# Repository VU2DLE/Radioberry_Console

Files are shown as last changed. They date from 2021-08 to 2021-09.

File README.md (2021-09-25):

<p align="center">
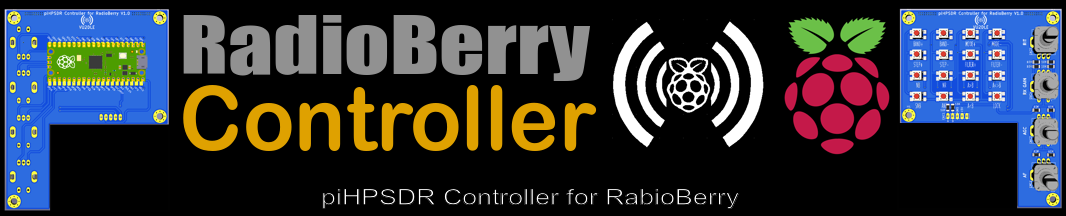
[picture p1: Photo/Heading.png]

</p>

Radioberry Controller is very simple standalone console for piHPSDR, which is designed only for RadioBerry SDR project. A simple way to control piHPSDR using hardware controls mounted in front panel. Both software and hardware initial version is ready to use, but still development is progressing, new features may get added and bugs being fixed. 

My sincere thanks to Johan for the RadioBerry SDR project, John Melton for piHPSDR.
Rama VU3RDD and Deepu VU3TLD for suggestions and design reviews from the beginning of this project.

## Version V1.0 Features
* VFO controlled by single optical encoder
* AF, AGC, RX GAIN and RIT controlled by 4 mechanical encoders
* Push Switch controls for
  * Band+, Band–
  * Mode+, Mode-
  * Step+, Step–
  * Filter+, Filter–
  * Noise functions: NB, NR ANF and SNB
  * VFO functions: VFO A to B, VFO B to A, VFO swap and Lock

## How it works
Radioberry Controller (RBC) PCB and Raspberry Pi Pico (Pico) works from the Raspberry Pi's (RPI) USB power. Pico is the part of RBC, and connects to the RPI using a USB cable. RBC takes 5V from the USB, so no need of external DC power. RBC reads the user events like switch press and movement of rotary encoder via GPIO's of the Pico. These user inputs are processed by Pico and send to Raspberry Pi via USB interface.
In RPI, application software rbc_comm, which receives the user response commands (like clicking switches or rotation of vfo encoder) via USB and send appropriate CAT commands to piHPSDR. USB serial adapter may appear as /dev/ttyACM0 in RPI, after pluging in Pico via USB cable.
<p align="center">
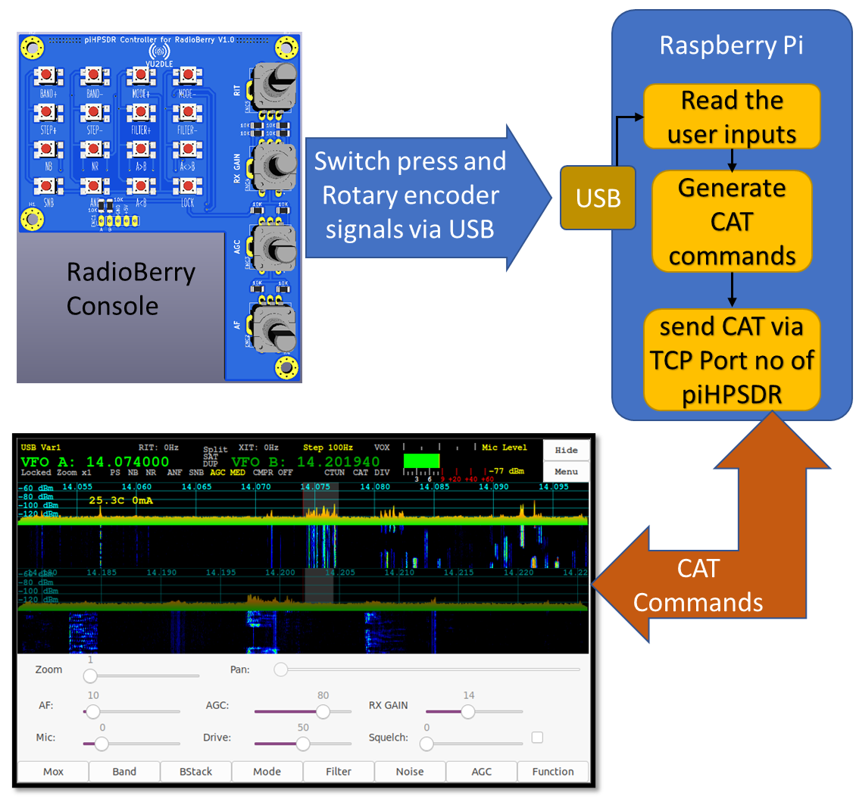
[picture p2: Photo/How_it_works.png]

</p>

## Hardware
Hardware is very simple. Solder the 4 mechanical encoder and 16 push buttons switch on the top of the PCB, also place the 10K resistors.
<p align="center">
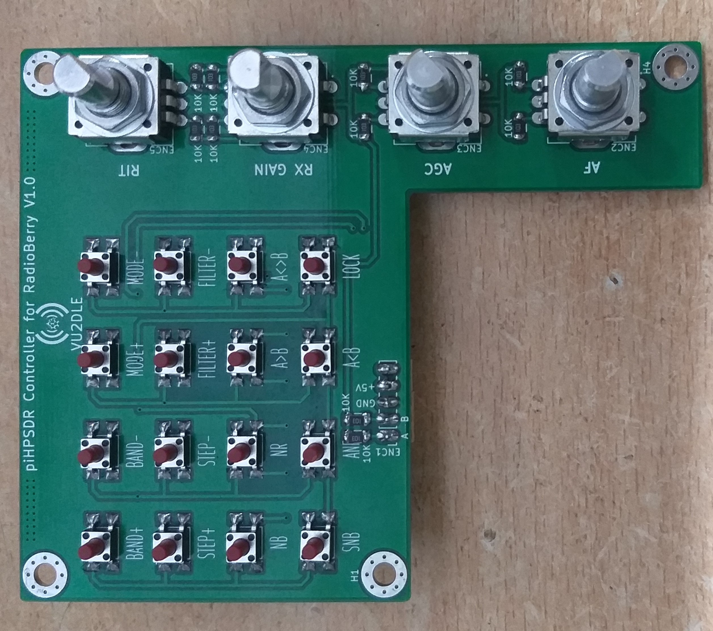
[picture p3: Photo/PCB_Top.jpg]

</p>
At the bottom, use appropriate PCB Receptacles Female Box Header Connector for placing the Raspberry Pi Pico. Luckily, I got cheap inexpensive connectors from local shop. Take 2 sets of, 18 way 1 row straight PCB female socket, through hole type. Carefully bend the leads 90degree and solder them.
<p align="center">
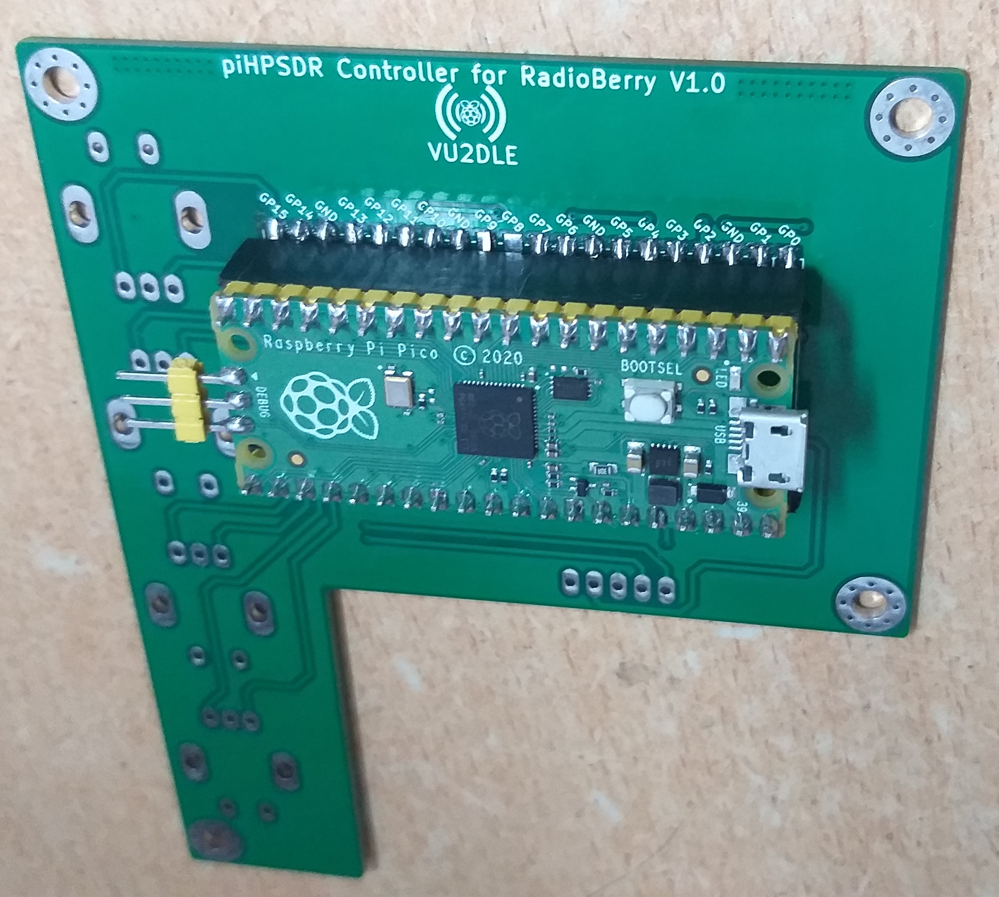
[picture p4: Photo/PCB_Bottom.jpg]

</p>

### Completely assembled PCB with optical rotary encoder
<p align="center">
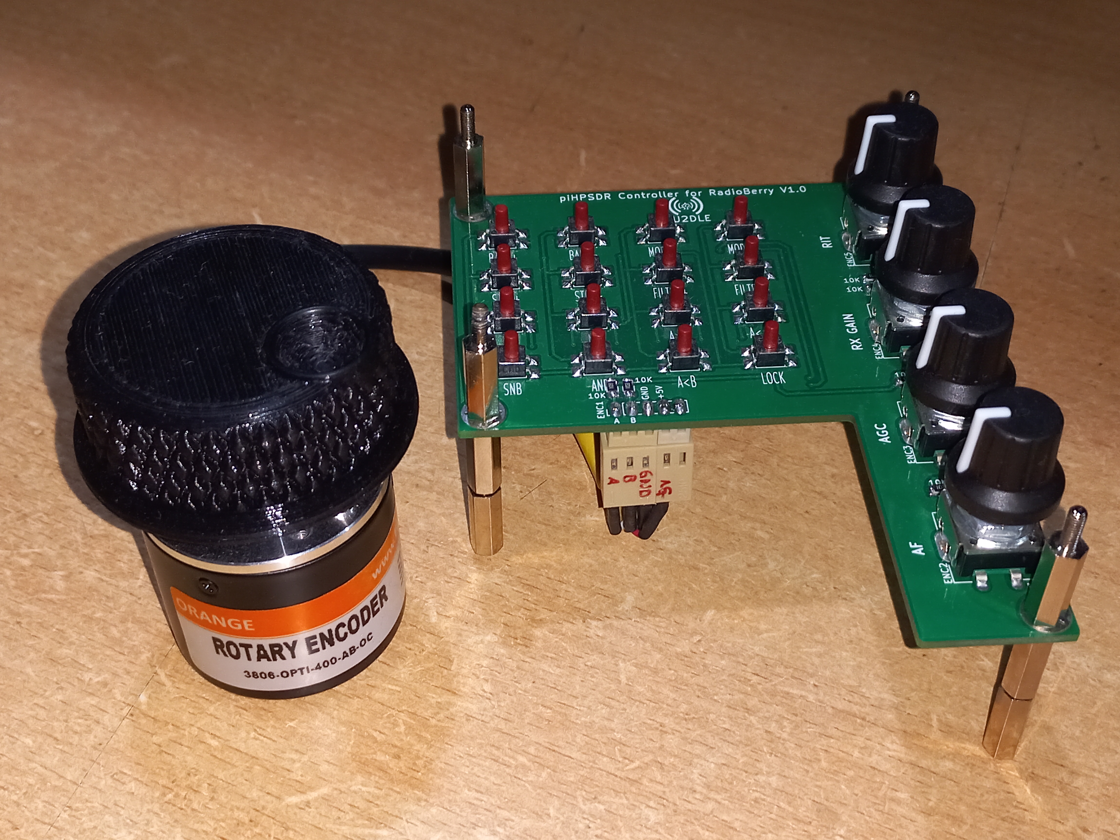
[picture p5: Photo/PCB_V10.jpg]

</p>

## Software Installation
Create a directory in your raspberry pi under the /home/pi. 
Open a command window and executing the following commands:
```ruby
cd /home/pi/
mkdir rbc_main
cd rbc_main
git clone https://github.com/VU2DLE/Radioberry_Console.git
```
### Step1: Flashing the firmware
Flashing the firmware in Pico is simple. Easy method is, if you hold down the BOOTSEL button when you plug in your Pico, it will appear as a drive onto which you can drag UF2 file. The binary file: rb_controller.uf2, is available in the folder rbc_main \Radioberry_Console\Software\Firmware\bin.
### Step2: Building the Application
Go to the folder “Application”
```ruby
cd /home/pi/rbc_main/Radioberry_Console/Software/Application/
make clean
make
```
### Step3: Rebuild the piHPSDR
There are few changes I have done in the rigctl.c of the piHPSDR, which is essential. since my pull request is not yet part of the /g0orx/pihpsdr, you can use the forked pihpsdr from my github.
Simple method to rebuild the piHPSDR is by editing pihpsdr_install.sh from Johan. Follow the steps of Johan for installing piHPSDR sofware.
Before executing “sudo chmod +x pihpsdr_install.sh”, open the pihpsdr_install.sh in any editor you are familiar, then remove line “git clone https://github.com/g0orx/pihpsdr.git”. Add “git clone https://github.com/VU2DLE/pihpsdr.git”. Save and close the pihpsdr_install.sh and continue remaining steps.

### Now software installation is completed.
Before executing the rbc_comm, make sure that radioberry is running and also pihpsdr. In pihpsdr, goto Menu->RIGCTL. rbc_comm program communicate piHPSDR via this TCP Port number 19090. Select Rigctl Enable tick mark and Rigctl Port Number is 19090.

Now Open a command window and execute the program
```ruby
cd /home/pi/rbc_main/Radioberry_Console/Software/Application/
./rbc_comm
```
Now you see the following output in the command window
```ruby
/*******************************************/
/**          W E L C O M E                **/
/**               T O                     **/
/**  piHPSDR Controller for Radioberry    **/
/**               V1.0                    **/
/**-------------------------------------- **/
/**          DE VU2DLE Dileep             **/
/*******************************************/
```

Radioberry_Console (https://www.youtube.com/watch?v=Wp12q2RIvMo)

Enjoy and Happy Homebrewing….

Many 73s
DE VU2DLE Dileep

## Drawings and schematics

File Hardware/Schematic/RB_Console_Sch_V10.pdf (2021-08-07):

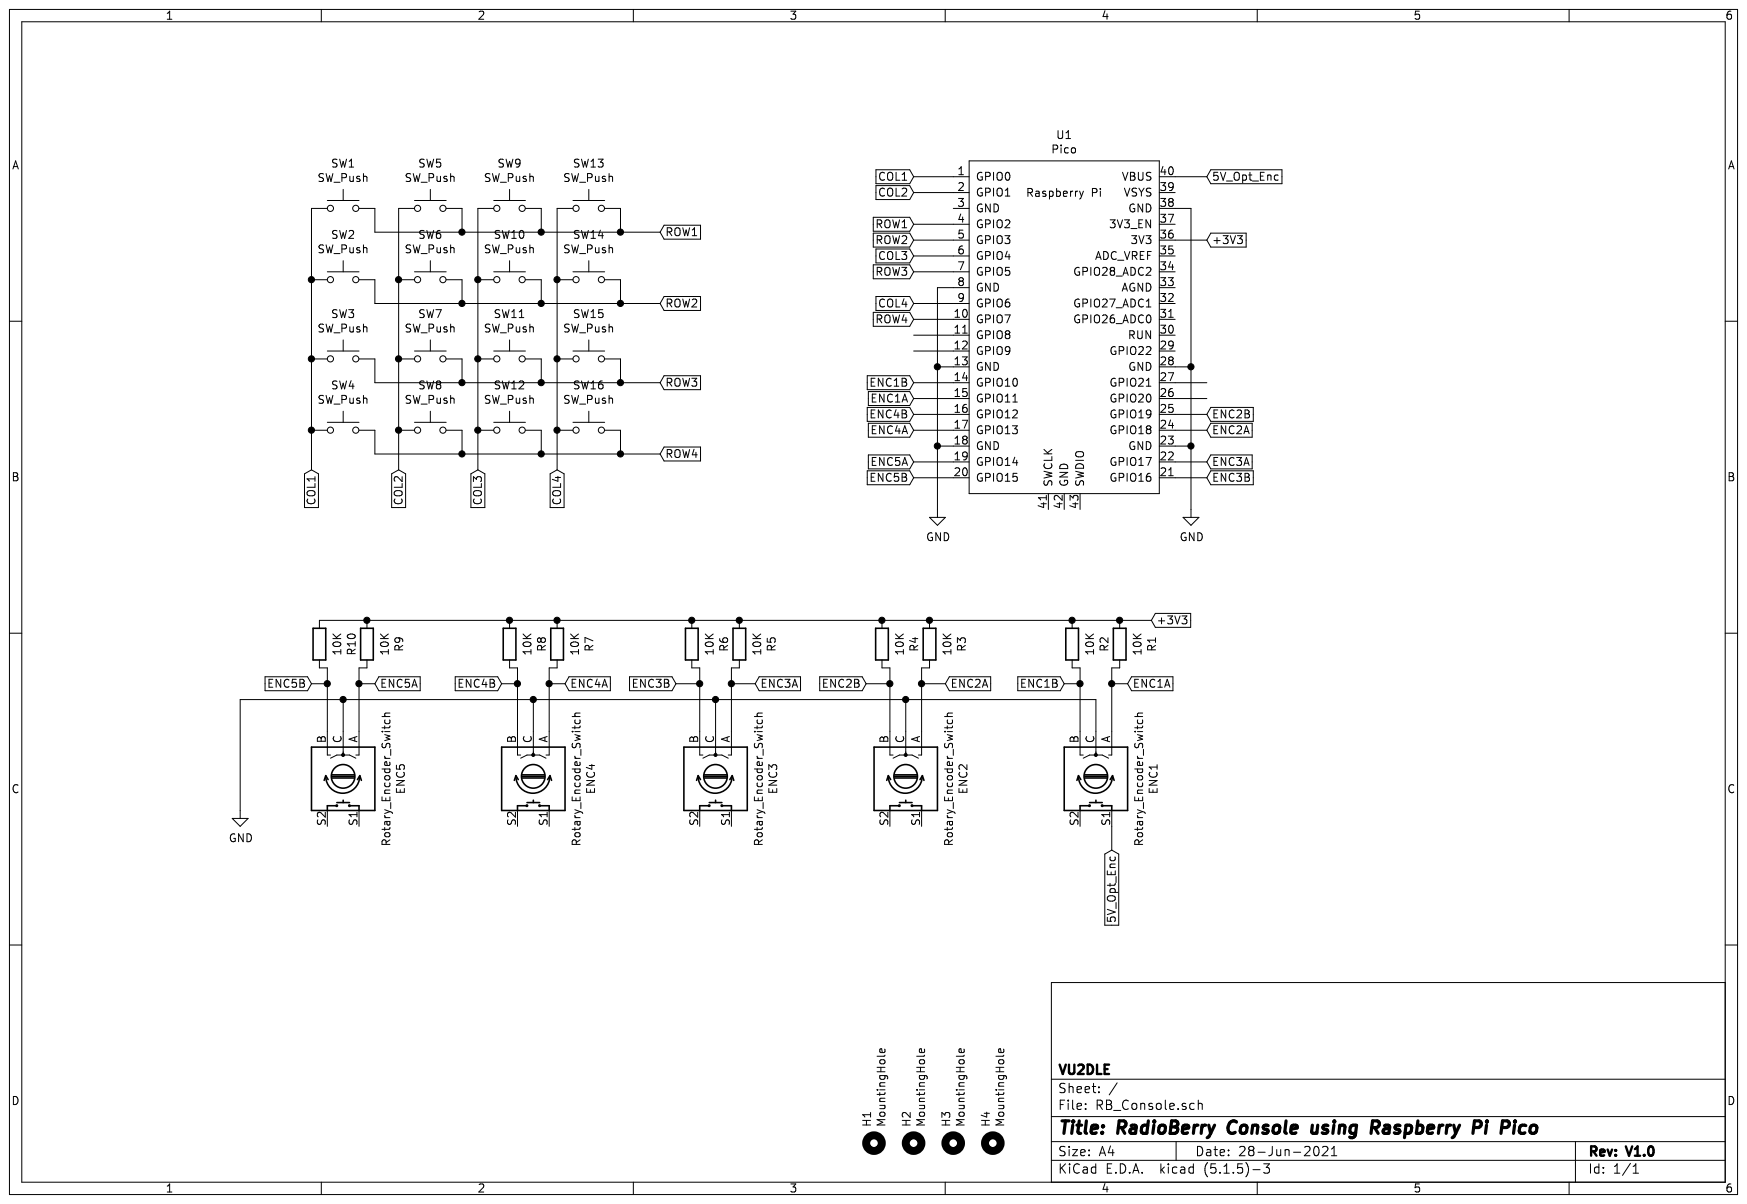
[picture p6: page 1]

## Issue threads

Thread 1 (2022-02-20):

Compile Radioberry console on Rpi4

PeWa1, 2022-02-20:
I  have problem to find lpthread and lwiringPi on Raspberry Debian Bullseye 64bit
WiringPi seams to exclude lib files, can you post them here ?

VU2DLE, 2022-02-23:
OM SM6NTR,

I haven't tried the latest build for rpi4. would you mind giving details about the latest build? then I can re-create the same issue that you are facing, which may help me to solve issue fast.

My RPI is RPI4B

My RPI4 OS Version:
pi@raspberrypi:~ $ cat /etc/os-release
PRETTY_NAME="Raspbian GNU/Linux 10 (buster)"
NAME="Raspbian GNU/Linux"
VERSION_ID="10"
VERSION="10 (buster)"
VERSION_CODENAME=buster
ID=raspbian
ID_LIKE=debian
HOME_URL="http://www.raspbian.org/"
SUPPORT_URL="http://www.raspbian.org/RaspbianForums"
BUG_REPORT_URL="http://www.raspbian.org/RaspbianBugs"

I'm getting no clue on how "multiple definition of buffer" issues are popping. could you please try following commands in rpi4 and let me share your log?

cd /home/pi/rbc_main/Radioberry_Console/Software/Application/
make clean
make

Many 73s
DE VU2DLE Dileep

PeWa1, 2022-02-23:
Hello Dileep
Here is my setup

pi@raspberrypi:~ $ cat /etc/os-release
PRETTY_NAME="Raspbian GNU/Linux 11 (bullseye)"
NAME="Raspbian GNU/Linux"
VERSION_ID="11"
VERSION="11 (bullseye)"
VERSION_CODENAME=bullseye
ID=raspbian
ID_LIKE=debian
HOME_URL="http://www.raspbian.org/"
SUPPORT_URL="http://www.raspbian.org/RaspbianForums"
BUG_REPORT_URL="http://www.raspbian.org/RaspbianBugs"

Consol text from make

pi@raspberrypi:~/rbc_main/Radioberry_Console/Software/Application $ make clean
Cleaning up...
rm -rf rbc_comm.o button.o rbc_comm
pi@raspberrypi:~/rbc_main/Radioberry_Console/Software/Application $ make
gcc -c rbc_comm.c button.c -lpthread -lwiringPi
gcc -o rbc_comm rbc_comm.o button.o -lpthread -lwiringPi
/usr/bin/ld: button.o:(.bss+0x0): multiple definition of `buffer'; rbc_comm.o:(.bss+0x254): first defined here
/usr/bin/ld: button.o:(.bss+0x118): multiple definition of `n'; rbc_comm.o:(.bss+0x14): first defined here
collect2: error: ld returned 1 exit status
make: *** [Makefile:5: rbc_comm] Error 1
pi@raspberrypi:~/rbc_main/Radioberry_Console/Software/Application $ ls -l
total 44
-rw-r--r-- 1 pi pi 6273 Feb 20 15:26 button.c
-rw-r--r-- 1 pi pi   47 Feb 20 15:26 button.h
-rw-r--r-- 1 pi pi 9068 Feb 23 17:40 button.o
-rw-r--r-- 1 pi pi  200 Feb 20 15:26 Makefile
-rw-r--r-- 1 pi pi 6267 Feb 20 15:26 rbc_comm.c
-rw-r--r-- 1 pi pi 6912 Feb 23 17:40 rbc_comm.o
pi@raspberrypi:~/rbc_main/Radioberry_Console/Software/Application $

rems78, 2022-06-08:
for wiring pi , the solution could be here :
http://wiringpi.com/wiringpi-updated-to-2-52-for-the-raspberry-pi-4b/
but i still have alot of errror during compilation.
thus i start a new install from radioberry on RPI4 with ''old '' os.
https://www.raspberrypi.com/software/operating-systems/
os buster  32 bits
Raspberry Pi OS (Legacy) with desktop Release date: April 4th 2022
System: 32-bit Kernel version: 5.10 Debian version: 10 (buster)
Size: 751MB

no need to upgrade wiring pi during VU2DLE software installation
Installation seem to be ok, now

PeWa1, 2022-07-11:
Hello Dileep
I have testing the Console little more now , and I have notice some software stops during test
the sound also stop and the communication to Rapsbery pico stops , this is shortly around som minutes of using, today i connected to the local ip 127.0.0.1 on radioberry and then the panel software it runs Ok the whole day but i testet the volume control after some hours and it still runs OK , i wonder if you have seen any problems that i have, Pico software stops and sound stops sometime , the sound can however be restared from the pihpsdr menu sound on/off , but the pico sofware i have to start from run again is there any different to start pihpsdr from 127.0.0.1 or the network 192.168.xxx.xxx adress, i dont think so ? what is the most sensetive stop for pico software to pihpsdr can it be more robust communication ?  best 73 Peter / SM6NTR

rems78, 2023-02-11:
Hello
The only issu I have is  comming from the pihpsdr with rbc : ''pihpsdr mic_read_thread read from audio interface failed''
Message appears only if I start rbc_main, and if I use a mic in configuration.
Thus I can not use rbc and this hardware in transmit mode  :-(

rems78, 2023-02-16:
not really compilation issue, but  issue detected on RPI4 . With ''top'' command I discover that rbc_comm is using 200% of CPU. the mic mic_read_thread error in pihpsdr is canceled with audio mic on -off. Issue increase with Sample rate, duplex,  and if rbc-com is started.
is this ''200% cpu '' understandable? wrong indicator.?
best 73. Rémi  / F4BAD

OK2MTW, 2023-03-14:
Hello guys, I tried to compile app, and I had similar problem with multiple definition for variable n and buffer, both are in both *.c files. So I decided to change them in one of them and my compilation was successful. I am not tested it yet due to my HW will be finished  during a few days.
Martin OK2MTW

vu2iia, 2024-08-01:
HI Martin @OK2MTW
Thanks for the good tip, I was able to compile on "bullseye". Edited 'button.c' and code compiled fine, earlier had same issue of "multiple definition".
Mahesh-VU2IIA

SP2NNO, 2024-08-01:
Dear friend

1. I have a Raspberry Pi 4 with a 7-inch display, running Raspberry Pi OS. 

2. Additionally, I have installed a Radioberry board and the appropriate software.

3. I have installed pihpsdr, which works well. 

4. I also downloaded the software from https://github.com/VU2DLE/Radioberry_Console.git.

5. I ordered a PCB for the RBC controller, where I mounted all the components along with the Pi Pico processor, which has the rb_firmware_v10.uf2 program uploaded.

6. According to your instructions, I tried to compile the RBC application. However, I encountered an error due to the missing wiringPi library in the operating system. 

7. I found and installed the wiringpi-2.61-1-arm64.deb library.
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
SP2NNO, 2024-09-18:
Hello everyone on the forum. The lack of activity was due to the fact that I had just finished heart surgery. Yes, the console works flawlessly, only thanks to the help of my friend Bartek SP3CAI.  Dimitrij, if you still haven't solved the problem, please contact me at: marekfoterek@wp.pl and you will receive a file with the entire manual and a ready-made processor input by SP3CAI. Regards, Marek SP2NNO

UT4NJ, 2024-09-18:
Marek, I wrote to your e-mail, thank you in advance.
Regards Dima. UT4NJ. 73!!! GL!!!

UT4NJ, 2024-09-19:
I'm trying to just record on Pico according to SP3CAI instructions, it doesn't work, I must be completely dumb. I copied micropython-12-JAN-2021.uf2 file to Pico, disconnected and connected Pico, disk does not appear.
Tried several Pico boards, I don't see the disk.
What is my mistake?

DO7CZ-Christian, 2024-09-19:
Hallo Marek, ich habe da gleiche Problem wie Dima UT4NJ.
Ich würde dir auch eine E-Mail schreiben.
Christian DO7CZ 73.

DO7CZ-Christian, 2024-09-19:
Ich erhalte folgende Meldung

**pi@sdr:~/rbc_main/Radioberry_Console/Software/Application $** make
gcc -c rbc_comm.c button.c -lpthread -lwiringPi
gcc -o rbc_comm rbc_comm.o button.o -lpthread -lwiringPi
/usr/bin/ld: button.o:(.bss+0x0): multiple definition of `buffer'; rbc_comm.o:(.bss+0x254): first define  d here
/usr/bin/ld: button.o:(.bss+0x118): multiple definition of `n'; rbc_comm.o:(.bss+0x14): first defined he  re
collect2: error: ld returned 1 exit status
make: *** [Makefile:5: rbc_comm] Fehler 1
**pi@sdr:~/rbc_main/Radioberry_Console/Software/Application $** ls
button.c  button.h  button.o  Makefile  rbc_comm.c  rbc_comm.o

UT4NJ, 2024-09-20:
I tried again according to SP3CAI instructions, after copying micropython-12-JAN-2021.uf2 file to Pico disk does not appear, tried copying adafruit-circuitpython-raspberry_pi_pico-ru-9.1.4.uf2 to Pico , everything is fine CIRCUITPY disk appears.
Is it possible to do further steps in this variant ? and why I don't have CIRCUITPY disk after copying micropython-12-JAN-2021.uf2 ??? ?

sp3cai, 2024-09-20:
1. Read carefully, especially "installing CircuitPython"
   and "Creating and editing Code" from:

   https://learn.adafruit.com/welcome-to-

2  Download uf2 file from:

   https://circuitpython.org/board/raspberry_pi_pico/

   this is: adafruit-circuitpython-raspberry_pi_pico-en_US-9.1.4.uf2

3. Press key on Pico and connect to USB, then open key:

   You must see disk named RPI-RP2 (disk letter)

4. Drag uf2 file to this disk, then wait - new disk is open with name
   CIRCUITPY(disk letter)

5. Copy the contents of the lib directory to this disk (there should be
   an empty lib directory there), and the code.py file in the main 
   directory.

6. Turn Pico off and on.

7. Look for the COM port that appears when you turn on Pico. Now
   you can monitor the program running on this COM using a terminal  
   program, for example PuTTY (set the port speed to 115200).

8. If everything is OK, you can enable Pico in pihpsdr, and configure via
   the menu, midi tab, where you need to enable midi setting.
   Now, when you press a button, a detected event appears, which can be   
   assigned using a table to the appropriate pihpsdr function.
   The same is done by turning an encoder in turn.
   Details can be found in the pihpsdr manual.

   greetings from sp3cai.

sp3cai, 2024-09-20:
program You can found on:

https://framagit.org/remis732/pico2040midicontroller

DO7CZ-Christian, 2024-09-20:
vielen lieben dank für die Anleitung :+1:
bei mir hat es funktioniert :)
ich hoffe Dima du bekommst es auch zum laufen.
73 DO7CZ Christian und ein schönes Wochenende

lebalme2000, 2024-11-17:
Hello everyone,
I tried to install the VU2DLE solution but I can't do it because of a Wiring error that I don't know how to resolve. I then turned to the solution of a MIDI interface and there I succeeded - the Deelep hardware works well but I just have a problem with the RX GAIN which when I turn it directly puts the RX gain at 0 - I cannot increase the RX GAIN by turning the encoder.
Did you also have this problem, how did you resolve it?

UT4NJ, 2024-11-18:
Hi everyone! I have the same problem. I am not satisfied with the solution of this problem through Pihpsdr Midi and since I developed the controller VU2DLE, I think it would be very good if he solved this problem and updated the instructions for installing the controller. Not everyone knows how to work with code, many just repeat the design and do everything according to the author’s instructions. I strongly ask the author and I think many join my request that the developer update the manual. It is really very useful design and many repeat it and now have a problem. In advance thank you!
With respect to Dima UT4NJ.

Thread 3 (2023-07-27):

Any thoughts on using this with sBitx

elvisthedj, 2023-07-27:
Hello Dileep,

I have a few pcb's from this project, but never actually obtained a Radioberry. I do however have an sBitx 40 v2. I've seen messages from you on the uBitx mailing list from several years ago, so I thought you may have considered using this board with one of Ashar's radios. Have you? I would love to make this work with my sbitx. I'm currently designing the enclosure, so if you have any feedback, please reply.

Thanks and 73's from Montana, USA

VU2DLE, 2023-07-28:
Hello elvisthedj,

Thank you for your interest in my project. Unfortunately, I haven't considered sBitx or uBitx while designing my project. My focus was "only" for RadioBerry. I would be very happy if you can make necessary modifications to use my project for your sBitx/uBitx.

with you good luck for your enclosure designing!

Many 73s DE Dileep VU2DLE DL2AJ

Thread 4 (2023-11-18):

Facing same problem with instruction " make" .

PE1PWR, 2023-11-18:
Hi Balan,
Thanks for your great work you have done.
I have a same problem to use " **make**"  for the final the programming.

cd /home/pi/rbc_main/Radioberry_Console/Software/Application/
**make clean
make**
After **make** I get this error.

pi@raspberrypi:~/rbc_main/Radioberry_Console/Software/Application $ sudo make
gcc -c rbc_comm.c button.c -lthread -lwiringPi
gcc -o rbc_comm rbc_comm.o button.o -lthread -lwiringPi
/usr/bin/ld: button.o:(.bss+0x0): multiple definition of `buffer'; rbc_comm.o:(.bss+0x254): first defined here
/usr/bin/ld: button.o:(.bss+0x118): multiple definition of `n'; rbc_comm.o:(.bss+0x14): first defined here
/usr/bin/ld: cannot find -lthread
collect2: error: ld returned 1 exit status
make: *** [Makefile:5: rbc_comm] Fout 1

When I use Make in Get this information
CC = gcc

rbc_comm:
	${CC} -c rbc_comm.c button.c -lthread -lwiringPi
	${CC} -o rbc_comm rbc_comm.o button.o -lthread -lwiringPi
clean:
	@echo "Cleaning up..."
	rm -rf rbc_comm.o button.o rbc_comm

Terminal info:
./Makefile: 1: CC: not found
./Makefile: 3: rbc_comm:: not found
./Makefile: 4: -c: not found
./Makefile: 5: -o: not found
./Makefile: 6: clean:: not found
./Makefile: 7: @echo: not found
------------------
(program exited with code: 0)
Press return to continue

I am using Release date: May 3rd 2023
System: 32-bit
Kernel version: 6.1
Debian version: 11 (bullseye)
Size: 2,701MB

Hoop you can tell me what I am missing. Or how I can resolving this problem. I have allready make a compleet Red Pitaya transmitter. Now I like to make a compleet Radioberry from Johan also with your project.
PE1PWR
73s

PE1PWR, 2023-11-19:
Finaly I have made the same solution to compile it in a raspberry PI3 and copied the files to my Pi4. Everything works fine now. Diplee thanks for your good job.
PE1PWR
73's

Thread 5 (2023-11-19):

What version of RAspberry OS have you used for this project ?

DarrenRainer, 2023-11-19:
Hi Dileep,

 I have a working Raspberry Pi 4 using radioberry (16 version)  and Pihhpsdr . I have  followed your changes in the code to install the code for the console but get stuck because I am using 64bit raspberry pi desktop OS. I tried a 32bit version but then get told on installing raspberry OS that it is not compatible. Do I need to try this on a raspberry pi3 with 32bit OS or do I stick with the RAspberry PI 4 with 64bit OS ?

73s Darren G4VTQ

PE1PWR, 2023-12-02:
Hi Darren,
Try to type this in your config.txt
arm_bit64=0
I was facing the same problem. After that everything works.

By the way I have use a older Raspberry pi3 to makes that extra files for the controller. The program was developpe with Bullseye. I mean step 2 in readme. The newer OS can handle this point.
Step2: Building the Application
Go to the folder “Application”

cd /home/pi/rbc_main/Radioberry_Console/Software/Application/
make clean
make

Goodluck
PE1PWR Wim
73s

DarrenRainer, 2023-12-02:
Thanks Wim for the help. I will give it a go and see what happens. I have
both pi3 and pi4.

73s Darren

On Sat, 2 Dec 2023, 09:48 Wim Schilperoort, ***@***.***>
wrote:

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

PE1PWR, 2023-12-02:
Hi Darran,
I think this will help you. I was also some time busy to get the radioberry a live. If want to use this controller also you have use the PI3 with bullseye. If you use the instruction " make clean"  it will work on both pi3 and 4. But when you do the instruction " make"  its only works on a Pi3. What I have done after this files are made i have copied them to de pi4 in the correct folder Application under RBC_main/Radioberry_Console/Application. You will find there 7 files. When its not working after the instruction " make"  you only find 5 files.
I hope that you find a way to get it work. Its a nice project. I have now the Radioberry working. Also the controller Pico Pi and Arduino Nano for the right signals to handle the LPF and BPF relais. Some later I place pictures of the Radioberry on QRZ.com where you can also see my other project a Red Pitaya HF transmitter.
Good luck
PE1PWR
Wim
73's

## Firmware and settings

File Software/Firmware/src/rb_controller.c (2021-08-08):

/**************************************
 * piHPSDR Controller for Radioberry
 * firmware V1.0
 * DE VU2DLE Dileep
 **************************************/
#include <stdio.h>
#include "pico/stdlib.h"
#include "pico/sync.h"


#define ENC1A 11
#define ENC1B 10

#define ENC2A 18
#define ENC2B 19

#define ENC3A 17
#define ENC3B 16

#define ENC4A 13
#define ENC4B 12

#define ENC5A 14
#define ENC5B 15

#define KPR0 2 
#define KPR1 3
#define KPR2 5
#define KPR3 7

#define KPC0 0
#define KPC1 1
#define KPC2 4
#define KPC3 6
#define KPCX 99 // undefined column number!

uint32_t int_status;

//--------------------------------------------------------------------------
#define DIR_NONE 0x0
// Clockwise step.
#define DIR_CW 0x10
// Anti-clockwise step.
#define DIR_CCW 0x20

#define R_START 0x0
//#define HALF_STEP

#ifdef HALF_STEP
// Use the half-step state table (emits a code at 00 and 11)
#define R_CCW_BEGIN 0x1
#define R_CW_BEGIN 0x2
#define R_START_M 0x3
#define R_CW_BEGIN_M 0x4
#define R_CCW_BEGIN_M 0x5
const unsigned char ttable[6][4] = {
  // R_START (00)
  {R_START_M,            R_CW_BEGIN,     R_CCW_BEGIN,  R_START},
  // R_CCW_BEGIN
  {R_START_M | DIR_CCW, R_START,        R_CCW_BEGIN,  R_START},
  // R_CW_BEGIN
  {R_START_M | DIR_CW,  R_CW_BEGIN,     R_START,      R_START},
  // R_START_M (11)
  {R_START_M,            R_CCW_BEGIN_M,  R_CW_BEGIN_M, R_START},
  // R_CW_BEGIN_M
  {R_START_M,            R_START_M,      R_CW_BEGIN_M, R_START | DIR_CW},
  // R_CCW_BEGIN_M
  {R_START_M,            R_CCW_BEGIN_M,  R_START_M,    R_START | DIR_CCW},
};
#else
// Use the full-step state table (emits a code at 00 only)
#define R_CW_FINAL  0x1
#define R_CW_BEGIN  0x2
#define R_CW_NEXT   0x3
#define R_CCW_BEGIN 0x4
#define R_CCW_FINAL 0x5
#define R_CCW_NEXT  0x6

const unsigned char ttable[7][4] = {
  // R_START
  {R_START,    R_CW_BEGIN,  R_CCW_BEGIN, R_START},
  // R_CW_FINAL
  {R_CW_NEXT,  R_START,     R_CW_FINAL,  R_START | DIR_CW},
  // R_CW_BEGIN
  {R_CW_NEXT,  R_CW_BEGIN,  R_START,     R_START},
  // R_CW_NEXT
  {R_CW_NEXT,  R_CW_BEGIN,  R_CW_FINAL,  R_START},
  // R_CCW_BEGIN
  {R_CCW_NEXT, R_START,     R_CCW_BEGIN, R_START},
  // R_CCW_FINAL
  {R_CCW_NEXT, R_CCW_FINAL, R_START,     R_START | DIR_CCW},
  // R_CCW_NEXT
  {R_CCW_NEXT, R_CCW_FINAL, R_CCW_BEGIN, R_START},
};
#endif

unsigned char ENC1state, ENC2state, ENC3state, ENC4state, ENC5state;
volatile int  ENC1NewState, ENC2NewState, ENC3NewState, ENC4NewState, ENC5NewState;
volatile int  KeyPressed =  false, Keyval = 0;
unsigned int col;
volatile uint kp_gpio = KPCX;
//unsigned int Keyval = 0;
unsigned int keypad_Row[4] = { KPR0, KPR1, KPR2, KPR3 };
unsigned int keypad_4X3[4][4] = {
                                  { 1,  2,  3,  4  }, 
                                  { 5,  6,  7,  8  }, 
                                  { 9,  10, 11, 12 }, 
                                  { 13, 14, 15, 16 }
                                };
// char keypad_msg[16][5] = {
//   "KM01", "KM02", "KM03", "KM04",  // { 1,  2,  3,  4 }
//   "KM05", "KM06", "KM07", "KM08",  // { 5,  6,  7,  8 }
//   "KM09", "KM10", "KM11", "KM12",  // { 9, 10, 11, 12 }
//   "KM13", "KM14", "KM15", "KM16"   // {13, 14, 15, 16 }
// };

char keypad_msg[16][5] = {
  "KM04", "KM08", "KM12", "KM16",  // { 1,  2,  3,  4 }
  "KM03", "KM07", "KM11", "KM15",  // { 5,  6,  7,  8 }
  "KM02", "KM06", "KM10", "KM14",  // { 9, 10, 11, 12 }
  "KM01", "KM05", "KM09", "KM13"   // {13, 14, 15, 16 }
};


void ENC1_Handler() {
  int s = 0;  
  int_status = save_and_disable_interrupts();
  if (ENC1NewState == 32)  {s = 1; }
  if (ENC1NewState == 16)  {s = -1;}
  ENC1NewState = 0;
  restore_interrupts(int_status);
  
  if(s != 0) {
    //Take action here 
    if (s == 1) {printf("EARI\n");}
    if (s == -1) {printf("EALE\n");}
  } 
}
void ENC2_Handler() {
  int s = 0;  
  int_status = save_and_disable_interrupts();
  if (ENC2NewState == 32)  {s = 1; }
  if (ENC2NewState == 16)  {s = -1;}
  ENC2NewState = 0;
  restore_interrupts(int_status);
  
  if(s != 0) {
    //Take action here 
    if (s == 1) {printf("EBRI\n");}
    if (s == -1) {printf("EBLE\n");}
  } 
}
void ENC3_Handler() {
  int s = 0;  
  int_status = save_and_disable_interrupts();
  if (ENC3NewState == 32)  {s = 1; }
  if (ENC3NewState == 16)  {s = -1;}
  ENC3NewState = 0;
  restore_interrupts(int_status);
  
  if(s != 0) {
    //Take action here 
    if (s == 1) {printf("ECRI\n");}
    if (s == -1) {printf("ECLE\n");}
  } 
}
void ENC4_Handler() {
  int s = 0;  
  int_status = save_and_disable_interrupts();
  if (ENC4NewState == 32)  {s = 1; }
  if (ENC4NewState == 16)  {s = -1;}
  ENC4NewState = 0;
  restore_interrupts(int_status);
  
  if(s != 0) {
    //Take action here 
    if (s == 1) {printf("EDRI\n");}
    if (s == -1) {printf("EDLE\n");}
  } 
}
void ENC5_Handler() {
  int s = 0;  
  int_status = save_and_disable_interrupts();
  if (ENC5NewState == 32)  {s = 1; }
  if (ENC5NewState == 16)  {s = -1;}
  ENC5NewState = 0;
  restore_interrupts(int_status);
  
  if(s != 0) {
    //Take action here 
    if (s == 1) {printf("EERI\n");}
    if (s == -1) {printf("EELE\n");}
  } 
}
void keypad_Handler() {
    gpio_put(KPR0, 0); gpio_put(KPR1, 0); gpio_put(KPR2, 0); gpio_put(KPR3, 0);
    if(kp_gpio == KPC0) col = 0; else if(kp_gpio == KPC1) col = 1; 
    else if(kp_gpio == KPC2) col = 2; else if(kp_gpio == KPC3) col = 3;
    for (unsigned int row = 0; ((row < 4) && (!Keyval)); row ++)
    {
      gpio_put(keypad_Row[row], 1);
      if (gpio_get(kp_gpio)) {
        sleep_ms(150);
        if (gpio_get(kp_gpio)) {
          Keyval = keypad_4X3[row][col]; 
          KeyPressed = true;
        }
      }
      gpio_put(keypad_Row[row], 0);
    }
    gpio_put(KPR0, 1); gpio_put(KPR1, 1); gpio_put(KPR2, 1); gpio_put(KPR3, 1);

    if (KeyPressed) {
      keypad_msg[Keyval - 1][4] = '\0';
      printf("%s\n", keypad_msg[Keyval - 1]);
      Keyval = 0; KeyPressed = false;
      kp_gpio = KPCX; 
    }
}

//--------------------------------------------------------------------------
void ENC1_callback_Handler(void) {
    unsigned char pinstate = (gpio_get(ENC1B) << 1) | gpio_get(ENC1A);
    // Determine new state from the pins and state table.
    ENC1state = ttable[ENC1state & 0xf][pinstate];
    // Return emit bits, ie the generated event
    pinstate = ENC1state & 0x30;
    if (pinstate) {ENC1NewState = (int)pinstate;}
}
void ENC2_callback_Handler(void) {
    unsigned char pinstate = (gpio_get(ENC2B) << 1) | gpio_get(ENC2A);
    // Determine new state from the pins and state table.
    ENC2state = ttable[ENC2state & 0xf][pinstate];
    // Return emit bits, ie the generated event
    pinstate = ENC2state & 0x30;
    //printf("pinstate = %d\n", pinstate);
    if (pinstate) {ENC2NewState = (int)pinstate;}
}
void ENC3_callback_Handler(void) {
    unsigned char pinstate = (gpio_get(ENC3B) << 1) | gpio_get(ENC3A);
    // Determine new state from the pins and state table.
    ENC3state = ttable[ENC3state & 0xf][pinstate];
    // Return emit bits, ie the generated event
    pinstate = ENC3state & 0x30;
    //printf("pinstate = %d\n", pinstate);
    if (pinstate) {ENC3NewState = (int)pinstate;}
}
void ENC4_callback_Handler(void) {
    unsigned char pinstate = (gpio_get(ENC4B) << 1) | gpio_get(ENC4A);
    // Determine new state from the pins and state table.
    ENC4state = ttable[ENC4state & 0xf][pinstate];
    // Return emit bits, ie the generated event
    pinstate = ENC4state & 0x30;
    //printf("pinstate = %d\n", pinstate);
    if (pinstate) {ENC4NewState = (int)pinstate;}
}
void ENC5_callback_Handler(void) {
    unsigned char pinstate = (gpio_get(ENC5B) << 1) | gpio_get(ENC5A);
    // Determine new state from the pins and state table.
    ENC5state = ttable[ENC5state & 0xf][pinstate];
    // Return emit bits, ie the generated event
    pinstate = ENC5state & 0x30;
    //printf("pinstate = %d\n", pinstate);
    if (pinstate) {ENC5NewState = (int)pinstate;}
}

void Keypad4X3_callback_Handler(uint gpio) {
  //printf("Keypad4X3_callback_Handler\n");
  kp_gpio = gpio;
}

void gpio_callback(uint gpio, uint32_t events) {
    //printf("gpio_callback gpio = %d\n",gpio);
    int_status = save_and_disable_interrupts();
    if( (gpio == ENC1A) || (gpio == ENC1B)) {
        ENC1_callback_Handler();
    }
    else if( (gpio == ENC2A) || (gpio == ENC2B)) {
        ENC2_callback_Handler();
    }
    else if( (gpio == ENC3A) || (gpio == ENC3B)) {
        ENC3_callback_Handler();
    }
    else if( (gpio == ENC4A) || (gpio == ENC4B)) {
        ENC4_callback_Handler();
    }
    else if( (gpio == ENC5A) || (gpio == ENC5B)) {
        ENC5_callback_Handler();
    }
    else if( (gpio == KPC0) || (gpio == KPC1) || (gpio == KPC2) || (gpio == KPC3)) {
        Keypad4X3_callback_Handler(gpio);
    }
    restore_interrupts(int_status);
}


int main() {

    stdio_init_all();

    //configuring Encoder1 A
    gpio_init(ENC1A);
    gpio_set_dir(ENC1A, GPIO_IN);
    gpio_pull_up(ENC1A);     
    //configuring Encoder1 B
    gpio_init(ENC1B);
    gpio_set_dir(ENC1B, GPIO_IN);
    gpio_pull_up(ENC1B);
    //ENC1 IRQ
    gpio_set_irq_enabled_with_callback(ENC1A, GPIO_IRQ_EDGE_RISE | GPIO_IRQ_EDGE_FALL, true, &gpio_callback);
    gpio_set_irq_enabled_with_callback(ENC1B, GPIO_IRQ_EDGE_RISE | GPIO_IRQ_EDGE_FALL, true, &gpio_callback);

    //configuring Encoder2 A
    gpio_init(ENC2A);
    gpio_set_dir(ENC2A, GPIO_IN);
    gpio_pull_up(ENC2A);     
    //configuring Encoder2 B
    gpio_init(ENC2B);
    gpio_set_dir(ENC2B, GPIO_IN);
    gpio_pull_up(ENC2B);
    //ENC2 IRQ
    gpio_set_irq_enabled_with_callback(ENC2A, GPIO_IRQ_EDGE_RISE | GPIO_IRQ_EDGE_FALL, true, &gpio_callback);
    gpio_set_irq_enabled_with_callback(ENC2B, GPIO_IRQ_EDGE_RISE | GPIO_IRQ_EDGE_FALL, true, &gpio_callback);

    //configuring Encoder3 A
    gpio_init(ENC3A);
    gpio_set_dir(ENC3A, GPIO_IN);
    gpio_pull_up(ENC3A);     
    //configuring Encoder3 B
    gpio_init(ENC3B);
    gpio_set_dir(ENC3B, GPIO_IN);
    gpio_pull_up(ENC3B);
    //ENC3 IRQ
    gpio_set_irq_enabled_with_callback(ENC3A, GPIO_IRQ_EDGE_RISE | GPIO_IRQ_EDGE_FALL, true, &gpio_callback);
    gpio_set_irq_enabled_with_callback(ENC3B, GPIO_IRQ_EDGE_RISE | GPIO_IRQ_EDGE_FALL , true, &gpio_callback);

    //configuring Encoder4 A
    gpio_init(ENC4A);
    gpio_set_dir(ENC4A, GPIO_IN);
    gpio_pull_up(ENC4A);     
    //configuring Encoder4 B
    gpio_init(ENC4B);
    gpio_set_dir(ENC4B, GPIO_IN);
    gpio_pull_up(ENC4B);
    //ENC4 IRQ
    gpio_set_irq_enabled_with_callback(ENC4A, GPIO_IRQ_EDGE_RISE | GPIO_IRQ_EDGE_FALL , true, &gpio_callback);
    gpio_set_irq_enabled_with_callback(ENC4B, GPIO_IRQ_EDGE_RISE | GPIO_IRQ_EDGE_FALL , true, &gpio_callback);

    //configuring Encoder5 A
    gpio_init(ENC5A);
    gpio_set_dir(ENC5A, GPIO_IN);
    gpio_pull_up(ENC5A);     
    //configuring Encoder5 B
    gpio_init(ENC5B);
    gpio_set_dir(ENC5B, GPIO_IN);
    gpio_pull_up(ENC5B);
    //ENC5 IRQ
    gpio_set_irq_enabled_with_callback(ENC5A, GPIO_IRQ_EDGE_RISE | GPIO_IRQ_EDGE_FALL , true, &gpio_callback);
    gpio_set_irq_enabled_with_callback(ENC5B, GPIO_IRQ_EDGE_RISE | GPIO_IRQ_EDGE_FALL , true, &gpio_callback);


    /* ----------------------- Configure 4X4 Keypad ------------------------------------*/
    gpio_init(KPC0);
    gpio_set_dir(KPC0, GPIO_IN);
    gpio_pull_down(KPC0); 
    gpio_init(KPC1);
    gpio_set_dir(KPC1, GPIO_IN);
    gpio_pull_down(KPC1); 
    gpio_init(KPC2);
    gpio_set_dir(KPC2, GPIO_IN);
    gpio_pull_down(KPC2);     
    gpio_init(KPC3);
    gpio_set_dir(KPC3, GPIO_IN);
    gpio_pull_down(KPC3); 
    gpio_set_irq_enabled_with_callback(KPC0,   GPIO_IRQ_EDGE_RISE, true, &gpio_callback);
    gpio_set_irq_enabled_with_callback(KPC1,   GPIO_IRQ_EDGE_RISE, true, &gpio_callback);
    gpio_set_irq_enabled_with_callback(KPC2,   GPIO_IRQ_EDGE_RISE, true, &gpio_callback);
    gpio_set_irq_enabled_with_callback(KPC3,   GPIO_IRQ_EDGE_RISE, true, &gpio_callback);

    gpio_init(KPR0);
    gpio_set_dir(KPR0, GPIO_OUT);
    gpio_put(KPR0, 1);
    gpio_init(KPR1);
    gpio_set_dir(KPR1, GPIO_OUT);
    gpio_put(KPR1, 1);
    gpio_init(KPR2);
    gpio_set_dir(KPR2, GPIO_OUT);
    gpio_put(KPR2, 1);
    gpio_init(KPR3);
    gpio_set_dir(KPR3, GPIO_OUT);
    gpio_put(KPR3, 1);
    /* ----------------------- Configure 4X4 Keypad ------------------------------------*/

    /* --- while(1) forever scheduler! --- */
    while (1)
    {
        ENC1_Handler();
        ENC2_Handler();
        ENC3_Handler();
        ENC4_Handler();
        ENC5_Handler();
        if(kp_gpio != KPCX) keypad_Handler();
    }
    return 0;
}

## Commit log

2021-08-07 initial folder structure update
    [RB_Console-B_Cu.gbl, RB_Console-B_Mask.gbs, RB_Console-B_SilkS.gbo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]
2021-08-07 pcb photo added
2021-08-07 pcb_v1.0 completed image added
